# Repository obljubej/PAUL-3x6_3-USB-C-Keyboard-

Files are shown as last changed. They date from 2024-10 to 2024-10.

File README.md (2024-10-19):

# Paul - Custom Split Keyboard

This project contains the PCB and Gerber files for a custom split keyboard, designed from the ground up using **KiCad** and **Ergogen**. Paul is a 42-key reversible PCB layout, tailored for ergonomic and customizable typing experiences. I currently use this keyboard as my primary device, and it has been a rewarding project from both a hardware and software perspective.

## Features
- **42-Key Reversible PCB Layout**: Designed to be efficient and minimal, the PCB supports both left and right halves of the split keyboard.
- **Custom Key Mapping Software**: Programmed using **QMK-MSYS**, **C++**, and **Python** for full customization of key mappings.
- **OLED Display**: Includes an OLED screen for additional visual feedback.
- **TRRS Jacks**: Easy connectivity between the two halves via TRRS jacks.
- **Fully Customizable Keycaps and Switches**: Tailored for your preferences.

## Hardware
- **PCB Design**: Created using **KiCad** and **Ergogen**, the PCB is compact and optimized for ergonomic usage.
- **Components Soldered**:
  - Resistors
  - Transistors
  - OLED Screen
  - TRRS Jacks
  - Keycaps
- **3D-Printed Case**: Designed and printed custom cases to house the PCB.

## Software
The keyboard firmware was developed using **Visual Studio** and leverages **QMK** for advanced key remapping and functionality. Here are some key details:
- **QMK-MSYS**: The keyboard firmware is programmable through QMK, allowing for endless customization of the key layout.
- **C++ and Python**: Used in conjunction with QMK for configuring macros, lighting, and OLED display outputs.

## PCB and Gerber Files
All the files necessary to fabricate your own Paul split keyboard are located in the `pcb/` directory of this repository.

## Getting Started
1. **Download the Gerber Files**: These are necessary for manufacturing the PCB. You can upload these files to any PCB manufacturer of your choice.
2. **Solder the Components**: Refer to the provided PCB design for where to solder the resistors, transistors, OLED screens, TRRS jacks, and key switches.
3. **Flash the Firmware**: Once the PCB is assembled, use QMK to program the firmware. Follow the instructions in the [QMK documentation](https://docs.qmk.fm/#/newbs) to get started with flashing.
4. **Assemble the Keyboard**: Use the provided 3D models to print a case that houses your keyboard and secures the components.

## Usage
This keyboard is fully customizable, and you can program custom keymaps to fit your workflow. Paul is currently in use as my daily keyboard, demonstrating its durability and functionality.

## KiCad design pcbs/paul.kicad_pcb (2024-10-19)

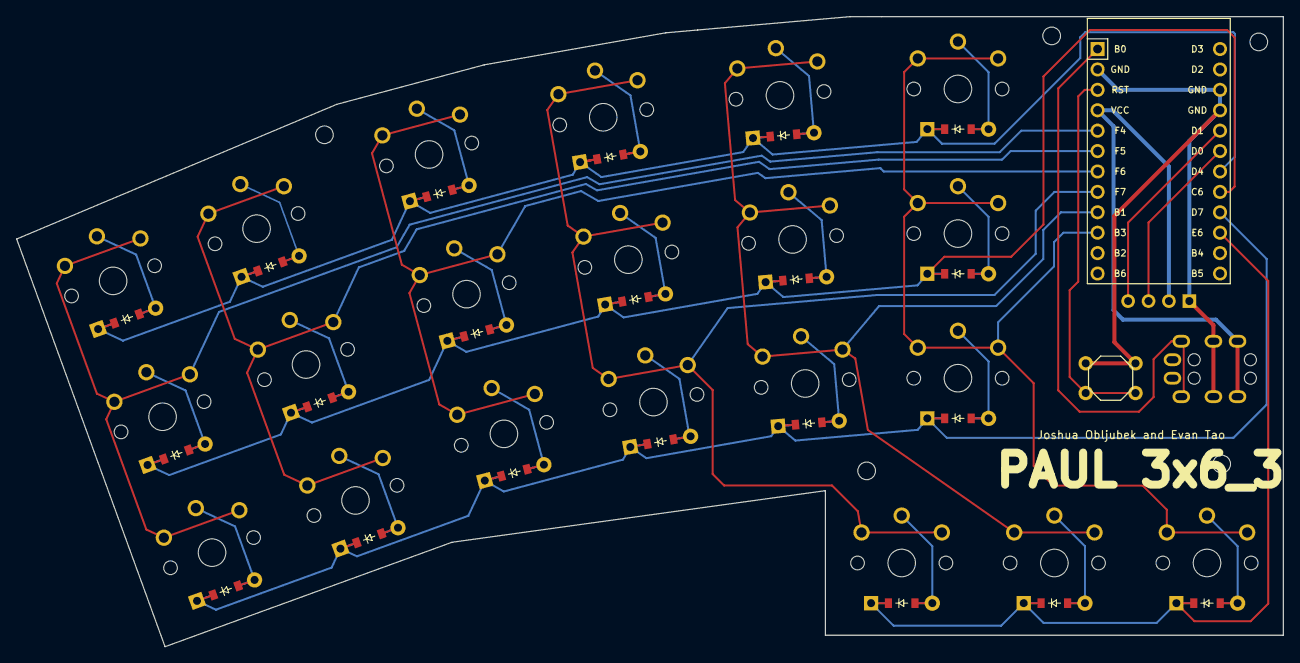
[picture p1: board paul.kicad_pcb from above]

Board: 2 copper layers, 157.7 x 78.4 mm, 46 parts (0 on the bottom side), 37 nets.

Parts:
B1: SW_TACT_ALPS_SKQGABE010
D1, D2, D3, D4, D5, D6, D7, D8, D9, D10, D11, D12, D13, D14, D15, D16, D17, D18, D19, D20, D21: ComboDiode
MCU1: ProMicro
OLED1: OLED; OLED_headers
S1, S2, S3, S4, S5, S6, S7, S8, S9, S10, S11, S12, S13, S14, S15, S16, S17, S18, S19, S20, S21: PG1350
TRRS1: TRRS-PJ-320A-dual

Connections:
B0: MCU1.1, TRRS1.2
B1: MCU1.9, S13.1, S14.1, S15.1, S20.1
B3: MCU1.10, S16.1, S17.1, S18.1, S21.1
C6: D2.1, D5.1, D8.1, D11.1, D14.1, D17.1, MCU1.20
D0: MCU1.18, OLED1.3
D1: MCU1.17, OLED1.4
D4: D3.1, D6.1, D9.1, D12.1, D15.1, D18.1, MCU1.19
D7: D1.1, D4.1, D7.1, D10.1, D13.1, D16.1, MCU1.21
E6: D19.1, D20.1, D21.1, MCU1.22
F4: MCU1.5, S1.1, S2.1, S3.1
F5: MCU1.6, S4.1, S5.1, S6.1
F6: MCU1.7, S7.1, S8.1, S9.1
F7: MCU1.8, S10.1, S11.1, S12.1, S19.1
GND: B1.1, MCU1.2, MCU1.15, MCU1.16, OLED1.1, TRRS1.1, TRRS1.3
RST: B1.2, MCU1.3
VCC: MCU1.4, OLED1.2, TRRS1.4
farPinky_bottom: D1.2, S1.2
farPinky_home: D2.2, S2.2
farPinky_top: D3.2, S3.2
far_thumb: D21.2, S21.2
home_thumb: D20.2, S20.2
index_bottom: D13.2, S13.2
index_home: D14.2, S14.2
index_top: D15.2, S15.2
inner_bottom: D16.2, S16.2
inner_home: D17.2, S17.2
inner_top: D18.2, S18.2
middle_bottom: D10.2, S10.2
middle_home: D11.2, S11.2
middle_top: D12.2, S12.2
near_thumb: D19.2, S19.2
pinky_bottom: D4.2, S4.2
pinky_home: D5.2, S5.2
pinky_top: D6.2, S6.2
ring_bottom: D7.2, S7.2
ring_home: D8.2, S8.2
ring_top: D9.2, S9.2
